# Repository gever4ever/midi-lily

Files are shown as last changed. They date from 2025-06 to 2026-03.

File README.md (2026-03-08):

# MIDI controller based on ATmega32U4 MCU

From concept to product - documentation and learning process

Documentating all the way of the supply chain from proof of concept to prototyping with custom breakout boards and producing the final PCB including design, layout, assembly and testing.

(Planned) Features:
- Sends standard MIDI messages 
- Rotary Encoders with pushbuttons
- Cherry MX switch matrix
- 45mm slider potentiometers
- RGB LED fader feedback

Specifications:
- ATmega32U4 MCU
- Native USB device and MIDI HID compliant 
- Type-C plug with over-current protection 
- MCP23S17 SPI GPIO expander for rotary encoders
- CD4067 16-channels multiplexer faders
- Shift registers for switch matrix scanning

Libraries used:
- FastLED
- ResponsiveAnalogRead
- MCP23X17
- CD4067

## 08.03.2026 - POD & Prototype

Prototype board was ordered through JLCPCB containing four "modules" of a rotary encoder, fader and three MX switches.  
Using a Teensy 2.0 and breakout boards of CD4067 multiplexer and SPI controlled MCP23S17 GPIO expander all functions and MIDI interface were confirmed working without noticeable delay using MIDI-OX on Windows monitoring incoming MIDI messages.

The setup was meant to have sub-optimal routing of signals and grounding to get a somewhat of an idea on how robust the signal integrity is.

Using 22AWG solid core wires for interconnects and a "prema-board" with 2.54mm socket headers soldered on.

### Prototype Photos

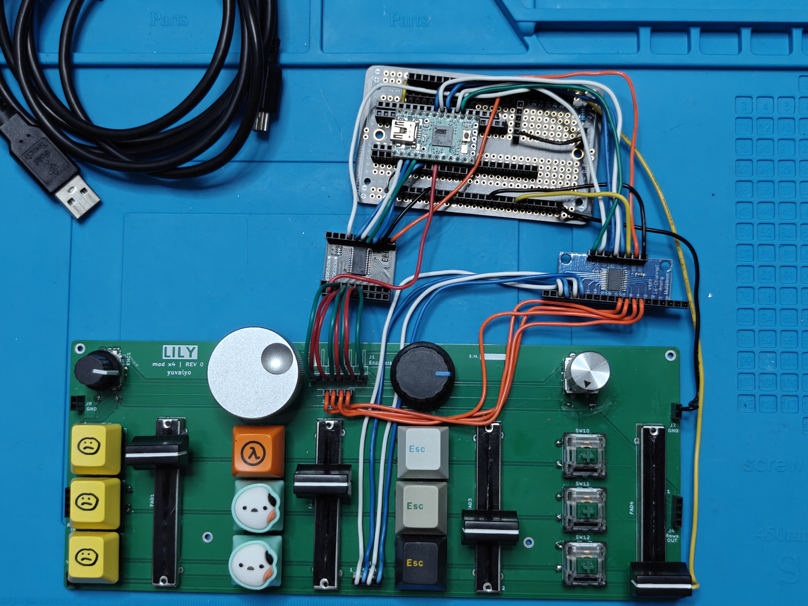
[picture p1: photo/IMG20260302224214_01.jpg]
Test Setup


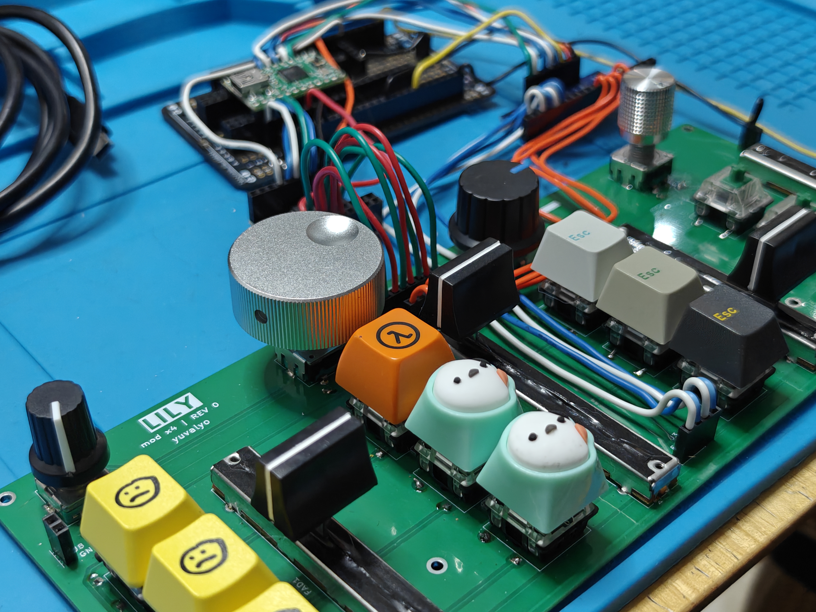
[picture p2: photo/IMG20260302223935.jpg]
Side view


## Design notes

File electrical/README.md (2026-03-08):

Production files compatible for JLCPCBs capabilities. Can be daisy chained to test a larger setup.
### Photos
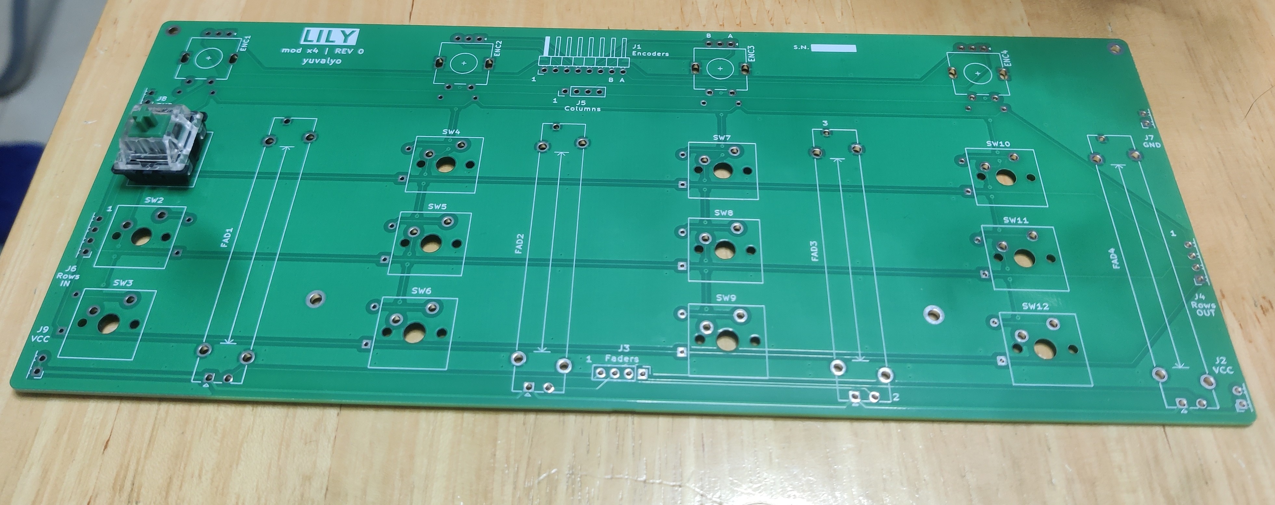
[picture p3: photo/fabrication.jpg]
Fabricated PCB


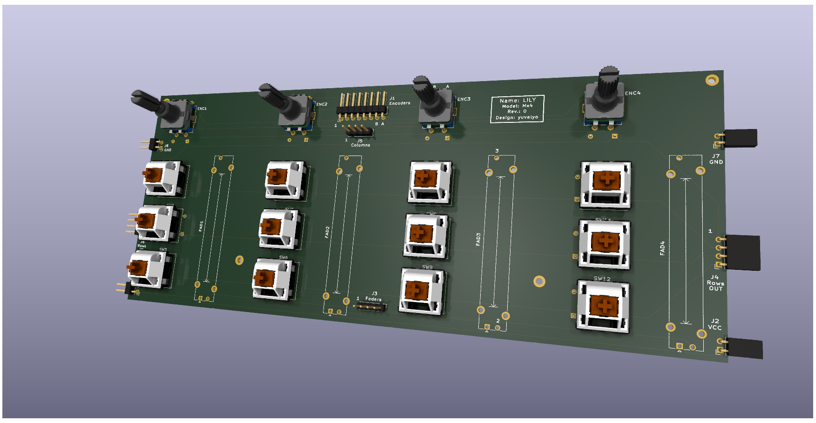
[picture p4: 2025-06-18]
electrical/production/midi_lily.png

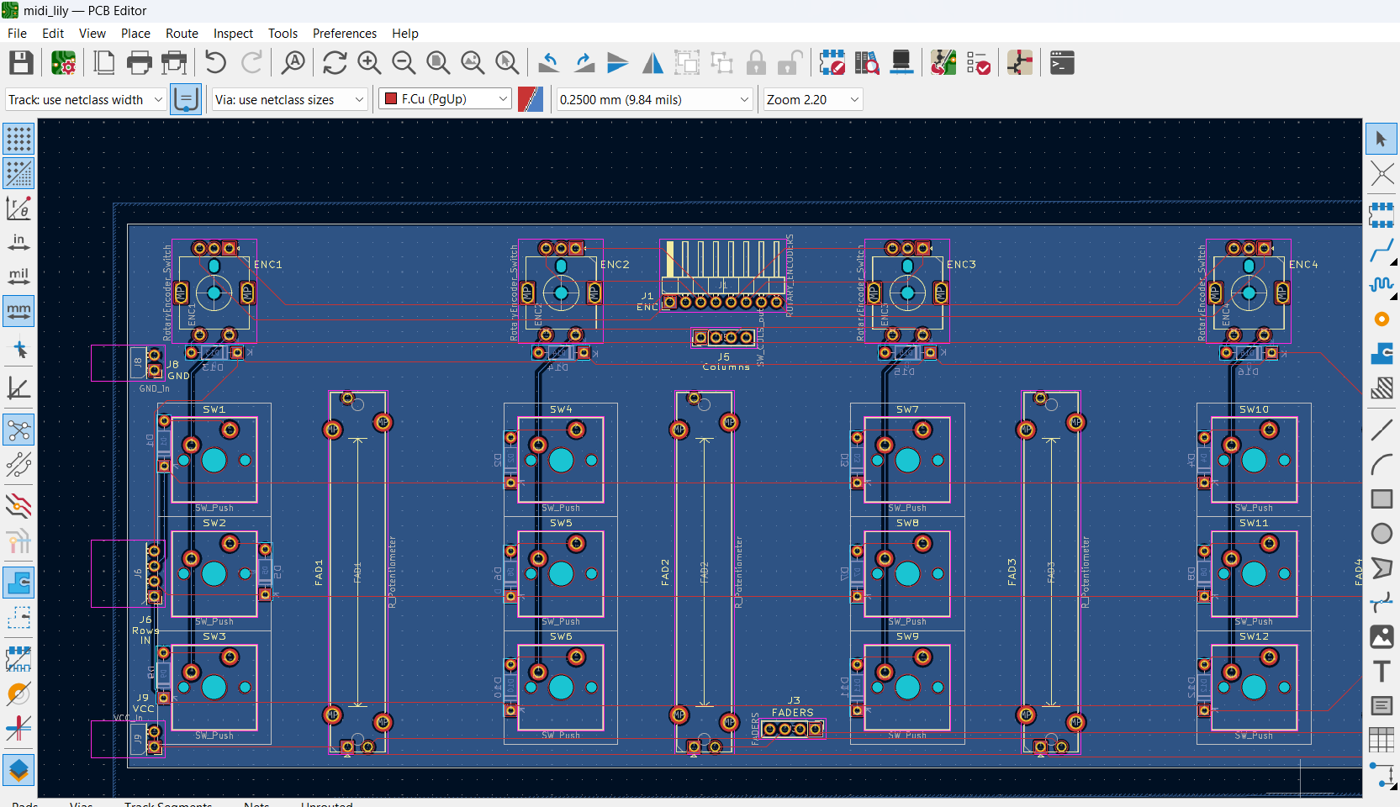
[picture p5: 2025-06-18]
electrical/layout.png

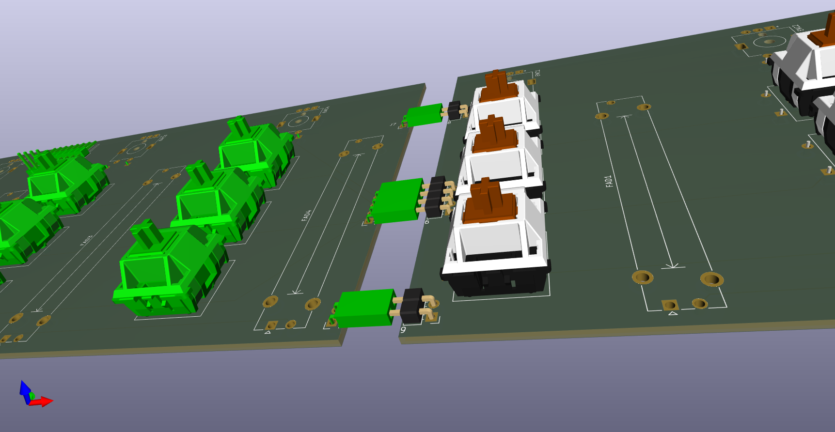
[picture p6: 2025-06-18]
electrical/interconnect.png

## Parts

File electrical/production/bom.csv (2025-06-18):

Designator | Footprint | Quantity | Value | LCSC Part #
D1, D10, D11, D12, D13, D14, D15, D16, D2, D3, D4, D5, D6, D7, D8, D9 | D_DO-35_SOD27_P7.62mm_Horizontal | 16 | D
ENC1, ENC2, ENC3, ENC4 | RotaryEncoder_Alps_EC11E-Switch_Vertical_H20mm | 4 | RotaryEncoder_Switch
FAD1, FAD2, FAD3, FAD4 | Potentiometer_Bourns_PTA4543_Single_Slide | 4 | R_Potentiometer
J1 | PinHeader_1x08_P2.54mm_Horizontal | 1 | ROTARY_ENCODERS
J2 | PinSocket_1x02_P2.54mm_Horizontal | 1 | VCC_out
J3 | PinHeader_1x04_P2.54mm_Vertical | 1 | FADERS
J4 | PinSocket_1x04_P2.54mm_Horizontal | 1 | SW_ROWS_out
J5 | PinHeader_1x04_P2.54mm_Vertical | 1 | SW_COLS_out
J6 | PinHeader_1x04_P2.54mm_Horizontal | 1 | SW_ROWS_in
J7 | PinSocket_1x02_P2.54mm_Horizontal | 1 | GND_out
J8 | PinHeader_1x02_P2.54mm_Horizontal | 1 | GND_in
J9 | PinHeader_1x02_P2.54mm_Horizontal | 1 | VCC_in
SW1, SW10, SW11, SW12, SW2, SW3, SW4, SW5, SW6, SW7, SW8, SW9 | SW_Cherry_MX_PCB_1.00u | 12 | SW_Push

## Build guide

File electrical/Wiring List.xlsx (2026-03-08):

Teensy | Board | CD4067 | Board | Teensy
A0 | FAD1 | C0 | ROW1
A1 | FAD2 | C1 | ROW2
A2 | FAD3 | C2 | ROW3
A3 | FAD4 | C3 | ROW4
A4 | COL1 | C4
A5 | COL2 | C5
A6 | COL3 | C6
A7 | COL4 | C7
A8 | ROW4 | C15 | FAD1
A9 | ROW3 | C14 | FAD2
A10 | ROW2 | C13 | FAD3
P11 | ROW1 | C12 | FAD4
P0 | ENC1_B | S0 |  | A4
P1 | ENC1_A | S1 |  | A5
P2 | ENC2_B | S2 |  | A6
P3 | ENC2_A | S3 |  | A7
P4 | ENC3_B | VCC |  | VCC
P5 | ENC3_A | GND | GND | GND
P6 | ENC4_B | SIG |  | A8
P7 | ENC4_A | EN |  | GND
 |  | MCP23S17 | Board | Teensy
 |  | A0 | ENC1_B
 |  | B0 | ENC1_A
 |  | A1 | ENC2_B
 |  | B1 | ENC2_A
 |  | A2 | ENC3_B
 |  | B2 | ENC3_A
 |  | A3 | ENC4_B
 |  | B3 | ENC4_A
 |  | VCC |  | VCC
 |  | GND |  | GND
 |  | SCK |  | P1
 |  | SI |  | P2
 |  | SO |  | P3
 |  | CS |  | P0
 |  | RESET |  | VCC
 |  | ITA |  | P5

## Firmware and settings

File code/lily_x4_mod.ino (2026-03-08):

/*

This is for reading the encoders over the GPIO expander and the faders over the multiplexer.
For testing purposes this was all written by Gemini.
Future firmwares would be optimized and more elegant. Probably.

*/

#include <SPI.h>

// ==================================================
// ---------------- CD4067 SETUP --------------------
// ==================================================

#define MUX_SIG A8
#define MUX_S0  A4
#define MUX_S1  A5
#define MUX_S2  A6
#define MUX_S3  A7

// CD4067 Channel Mapping
#define FAD1_CH 15
#define FAD2_CH 14
#define FAD3_CH 13
#define FAD4_CH 12

int lastFaderValue[4];

// ==================================================
// ---------------- MCP23S17 SETUP ------------------
// ==================================================

#define MCP_CS   0   // P0
#define MCP_INT  5   // P5 (unused for now)

#define MCP_IODIRA 0x00
#define MCP_IODIRB 0x01
#define MCP_GPIOA  0x12
#define MCP_GPIOB  0x13

byte encoderState[4];
byte lastEncoderState[4];

// ==================================================
// -------------------- SETUP -----------------------
// ==================================================

void setup() {

  // ---- MUX Control Pins ----
  pinMode(MUX_S0, OUTPUT);
  pinMode(MUX_S1, OUTPUT);
  pinMode(MUX_S2, OUTPUT);
  pinMode(MUX_S3, OUTPUT);

  pinMode(MUX_SIG, INPUT_PULLUP);

  // ---- SPI + MCP23S17 ----
  SPI.begin();
  pinMode(MCP_CS, OUTPUT);
  digitalWrite(MCP_CS, HIGH);

  initMCP();

  // Init fader memory
  for (int i = 0; i < 4; i++) {
    lastFaderValue[i] = readMuxAnalog(FAD1_CH - i);
  }
}

// ==================================================
// -------------------- LOOP ------------------------
// ==================================================

void loop() {

  readFaders();
  readEncoders();

  while (usbMIDI.read()) {}
}

// ==================================================
// ---------------- MUX FUNCTIONS -------------------
// ==================================================

void selectMuxChannel(byte channel) {
  digitalWrite(MUX_S0, channel & 0x01);
  digitalWrite(MUX_S1, (channel >> 1) & 0x01);
  digitalWrite(MUX_S2, (channel >> 2) & 0x01);
  digitalWrite(MUX_S3, (channel >> 3) & 0x01);
  delayMicroseconds(5);
}

int readMuxAnalog(byte channel) {
  selectMuxChannel(channel);
  return analogRead(MUX_SIG);
}

bool readMuxDigital(byte channel) {
  selectMuxChannel(channel);
  return !digitalRead(MUX_SIG); // active LOW (pullups)
}

// ==================================================
// ---------------- FADERS --------------------------
// ==================================================

void readFaders() {

  byte faderChannels[4] = {FAD1_CH, FAD2_CH, FAD3_CH, FAD4_CH};

  for (int i = 0; i < 4; i++) {

    int value = readMuxAnalog(faderChannels[i]);

    if (abs(value - lastFaderValue[i]) > 4) {

      int midiValue = map(value, 0, 1023, 0, 127);
      usbMIDI.sendControlChange(20 + i, midiValue, 1);

      lastFaderValue[i] = value;
    }
  }
}

// ==================================================
// ---------------- MCP23S17 ------------------------
// ==================================================

void initMCP() {

  writeMCP(MCP_IODIRA, 0xFF); // Port A inputs
  writeMCP(MCP_IODIRB, 0xFF); // Port B inputs
}

void writeMCP(byte reg, byte value) {

  digitalWrite(MCP_CS, LOW);
  SPI.transfer(0x40); // Write opcode
  SPI.transfer(reg);
  SPI.transfer(value);
  digitalWrite(MCP_CS, HIGH);
}

byte readMCP(byte reg) {

  digitalWrite(MCP_CS, LOW);
  SPI.transfer(0x41); // Read opcode
  SPI.transfer(reg);
  byte value = SPI.transfer(0x00);
  digitalWrite(MCP_CS, HIGH);

  return value;
}

// ==================================================
// ---------------- ENCODERS ------------------------
// ==================================================

void readEncoders() {

  byte gpioA = readMCP(MCP_GPIOA);
  byte gpioB = readMCP(MCP_GPIOB);

  for (int i = 0; i < 4; i++) {

    byte A = (gpioB >> i) & 1;
    byte B = (gpioA >> i) & 1;

    byte currentState = (A << 1) | B;

    if (currentState != lastEncoderState[i]) {

      if ((lastEncoderState[i] == 0b00 && currentState == 0b01) ||
          (lastEncoderState[i] == 0b01 && currentState == 0b11) ||
          (lastEncoderState[i] == 0b11 && currentState == 0b10) ||
          (lastEncoderState[i] == 0b10 && currentState == 0b00)) {

        usbMIDI.sendControlChange(30 + i, 1, 1);
      } else {
        usbMIDI.sendControlChange(30 + i, 127, 1);
      }

      lastEncoderState[i] = currentState;
    }
  }
}

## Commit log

2026-03-08 Update README with prototype board information
    Added details about the prototype board and its components.
2026-03-08 Code for four faders and four rotary encoders
    Used Gemini to generate a test firmware to interface with MCP23S17 GPIO expander and CD4067 multiplexer
2026-03-08 Wiring list for test setup
    [Wiring List.xlsx]
2026-03-08 Update image path for fabricated PCB in README
